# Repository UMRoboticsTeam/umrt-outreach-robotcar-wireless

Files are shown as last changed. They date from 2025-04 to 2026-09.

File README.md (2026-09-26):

# umrt-outreach-robotcar-wireless - elegoo-kit-face
Showcase program for the outreach car with wireless camera and control with the Elegoo Smart Robot Car Kit v4.0

The UI lets you control the car using the arrow keys (or controller) and displays a POV through the car's camera.
This repo also includes files to convert this into a POV soccer bot.

## elegoo-kit-face
This branch uses a modified version of the Elegoo Smart Robot Kit, replacing the ultrasonic sensor with an I2C OLED 128x64 Display.

<!-- ![alt text](docs/face-car.png) -->


This branch also contains the 3D printable files needed for the display modification.

### Additional Materials:
* I2C OLED Display 128x64
* 4x pin wires male to female
* 3D Printed Parts (files under ./3d-models)

The smart robot car kit shield contains a pin header for the gyroscope, which contains I2C communication pins A4 and A5. The gyroscope is not used in this program, so you can remove the gyroscope and use the pin header for OLED communication.

<!-- ![alt text](image-1.png) -->


### Soccer Bot
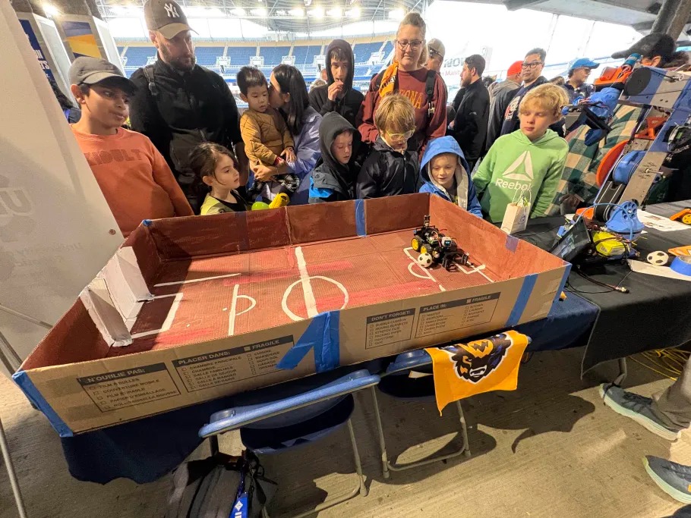
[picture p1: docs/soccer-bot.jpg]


*Soccer bot attechment in 3d-models/sumo_soccer_catch.3mf*

### Elegoo Smart Robot Car Kit v4.0

<!-- ![alt text](docs/smartrobotv4.0.png) -->
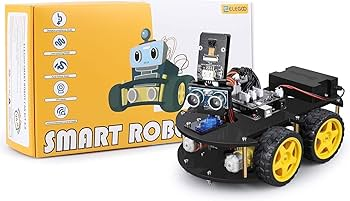
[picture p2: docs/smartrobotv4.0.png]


### Customized UI

<!-- ![alt text](docs/complete_ui.png) -->
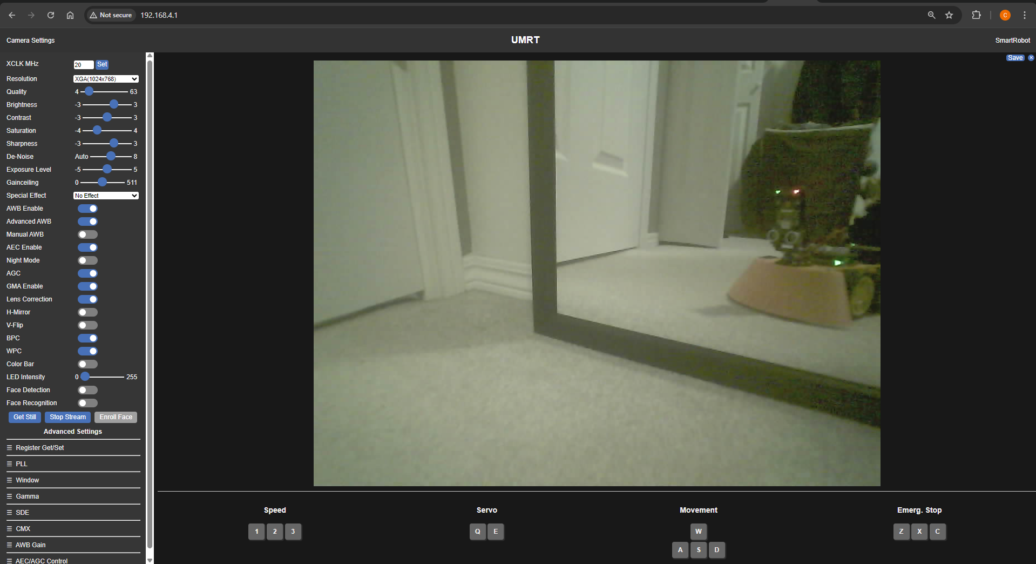
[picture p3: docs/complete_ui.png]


Has programs for:
* ESPCAM wireless webserver
* Robot car controller

## Source Code
[ELEGOO Smart Robot Car Kit v4.0 Tutorial](https://www.elegoo.com/blogs/arduino-projects/elegoo-smart-robot-car-kit-v4-0-tutorial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)
* Contains base code for motor controller - Be sure to check **Project Specifics**!

[ELEGOO Smart Robot Car V4.0 with Camera: Upload code to the camera module](https://www.elegoo.com/blogs/learn/elegoo-smart-robot-car-v4-0-with-camera-upload-code-to-the-camera-module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)
* Contains **UPDATED** camera code for the ESP32S3 Camera V1.0.

## Project Specifics
The template programs change depending on your specific parts. 
* ESP Camera: ```Elegoo ESP32S3 Camera v1.0```
* Motor Driver: ```TB6612```
* Gyro Module: ```MPU6050```

# car-driver
Arduino IDE Configuration:
* Board: ```Arduino UNO```

**Features:**  
* Adds OLED face functionality
* Improved UART communication from ESP32
* Added joystick motor control commands

<!-- ## ESP Camera Arduino IDE Setup -->
# ESP32_CameraServer_AP_2023_v1.3
Arduion IDE Configuration:
* Board Manager > Install ```esp32 by Espressif Systems v2.0.14```
* Configure Tools:
  * Board: ```ESP32S3 Dev Module```
  * USB CDC On Boot: ```Enabled```
  * Flash Size: ```8MB (64Mb)```
  * Partition Scheme: ```8M with spiffs (3MB APP/1.5MB SPIFFS)```
  * PSRAM ```OPI PSRAM```

The program creates a REST API to send json through to UART to the Arduino Uno to control the motors.

The served HTML handles all of the controls functionality. Based on the input, it will send json commands to the camera which forwards it to the robot car controller. The HTML file itself is stored as compressed GZ bytes under `camera_index.h`. To convert between a working HTML file and compressed bytes, use `converter.py`

## converter.py
Quick tool to convert HTML into compressed GZ bytes.

Used to compress **camera_index.html** into **camera_index.h**, to be compiled into the ESP32 webserver.
```
> python ./converter.py html_to_txt
```

`camera_index.h` and its variables are referenced during compilation, which stores all of the compressed HTML files.

To run the decompression process (`camera_index.h` to `camera_index.html`):
```
> python ./converter.py txt_to_html
```

# Usage
1. Turn on the power supply on the car, which powers both the car controller and the camera
2. Connect to the wifi called ```UMRT-CAR-XXXXXXXXXXXX```

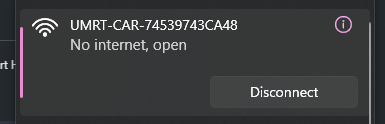
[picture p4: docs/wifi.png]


3. Open a browser and connect to ```192.168.4.1```
4. Configure settings by clicking the text in the top left
5. control the robot with your keyboard
  
| Key | Command |
|---|-----|
| Up | Move Forward |
| Down | Move Backward |
| Left | Turn Left |
| Right | Turn Right |
| Z, X, C | Emergency Stop |

Or connect a controller with a joystick! It can be used with one of them.  
The program assumes you will use:
* The first controller attached to the host device
* The axes [0] and [1] published by the controller

## Troubleshooting:
* If input is a little laggy: try turning it off and on again
* If the motor driver is stuck: try resetting it
* If the camera feed stops: try restarting car and browser

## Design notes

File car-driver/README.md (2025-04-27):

# car-driver

Custom car driver code for an Arduino UNO controlled by ESP32S3 Camera

Features expressive eyes powered by [Flux Garage's RoboEyes](https://github.com/FluxGarage/RoboEyes/) to add personality to the bot.

# Hardware
* Arduino UNO
* ESP32S3 Camera
* L298N Motor Driver (With 12V Power Supply)
* 4 Motors
* 128x64 I2C SSD1306 OLED Display
* Single servo motor

# Libraries

OLED Eyes:
https://github.com/FluxGarage/RoboEyes/

Motor Driver Lib:
https://github.com/AndreaLombardo/L298N

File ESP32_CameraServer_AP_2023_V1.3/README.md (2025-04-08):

# ESP32 CameraServer
Hosts webpage and REST API to pass json commands through UART to motor driver

I believe in older versions this code used ESP-FACE included in Core 2.0.0 and below, but its not included here. ESP Core 2.0.14 is required for ESP32-S3.

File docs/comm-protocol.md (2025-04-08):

# Communication Protocol
### ELEGOO - Smart Robot Car V4.0 With Camera
Copied from `Communication protocol for Smart Robot Car.pdf`

This was initially for the serial communication to the smart car, but since the REST API is implemented on the camera web server, you just need to send a POST request to the `/json_command` endpoint with your json command.

Not all commands are tested. 

# Motor
```json
{"H": ID, "N": 1, "D1": selection, "D2": speed, "D3": direction}
```
Select the motor to set the rotation direction and speed

| Parameter | Name | Description |
|----|-|-|
| D1 | Selection | 0: All Motors<br>1: Left Motors<br>2: Right Motors |
| D2 | Speed | Motor Speed 0-255 |
| D3 | Direction | 0: Clockwise<br>1: Counterclockwise |

```json
{"H": ID, "N": 3, "D1": direction, "D2": speed}
```
Set the direction and speed of the car
| Parameter | Name | Description |
|-|-|-|
| D1 | Direction | 1: Turn Left<br>2: Turn Right<br>3: Forward<br>4: Back |
| D2 | Speed | 0-255 |

```json
{"H": ID, "N": 3, "D1": left_speed, "D2": right_speed}
```
Set the speed of the left and right motors separately
| Parameter | Name | Description |
|-|-|-|
| D1 | Left Motor Speed | 0-255 |
| D2 | Right Motor Speed | 0-255 |

# Servo Motor
```json
{"H": ID, "N": 5, "D1": servo_id, "D2": angle}
```
Set the rotation angle of the servo motor
| Parameter | Name | Description |
|-|-|-|
| D1 | Servo ID | 0 or 1 |
| D2 | Rotation Angle | 0-180 |

## Camera Rotation (Wrapper of Servo Motor?)
```json
{"N": 106, "D1": direction}
```
Set the rotation direction of the camera
| Parameter | Name | Description |
|-|-|-|
| D1 | Direction | 1: Up<br>2: Down<br>3: Left<br>4: Right  |

# Clear Mode
```json
{"N": 100}
```
Clear all functions being executed.
```json
{"H": ID, "N": 110}
```
Clears all functions being executed, and does not enter standby mode

# Switch Car Mode
```json
{"N": 101, "D1": mode}
```
Switch the car mode
| Parameter | Name | Description |
|-|-|-|
| D1 | Mode | 1: Tracking mode<br>2: Obstacle-avoidance mode<br>3: Follow mode |

# Joystick Movement
```json
{"N": 102, "D1": direction, "D2": speed}
```
Make the car move in a certain direction
| Parameter | Name | Description |
|-|-|-|
| D1 | Direction | 1: Forward<br>2: Back<br>3: Turn Left<br>4: Turn Right<br>5: Left Forward<br>6: Left Back<br>7:Right Forward<br>8: Right Back|
| D2 | Speed | 0-255 |

# Ultrasonic Module
```json
{"H": ID, "N": 21, "D1": option}
```
Check whether an obstacle is detected
| Parameter | Name | Description |
|-|-|-|
| D1 | option | 1: Obstacle is detected? Returns `{ID_false}` or `{ID_true}`<br>2: Sensor Value? Returns `{ value }` |

# Infared Module
```json
{"H": ID, "N": 22, "D1": infared_id}
```
Check the value of the infared sensor
| Parameter | Name | Description |
|-|-|-|
| D1 | Infared ID | 0: Left Sensor<br>1: Middle Sensor<br>2: Right Sensor |
Returns `{ ID_ value }`

```json
{"H": ID, "N": 23}
```
Check if the car leaves the ground
Returns `{ ID_ false }` or `{ ID_ true }`

# Threshold Adjustment
```json
{"N": 104, "D1": value}
```
Adjust the tracking sensitivity of the car
| Parameter | Name | Description |
|-|-|-|
| D1 | Value | 50-1000 |

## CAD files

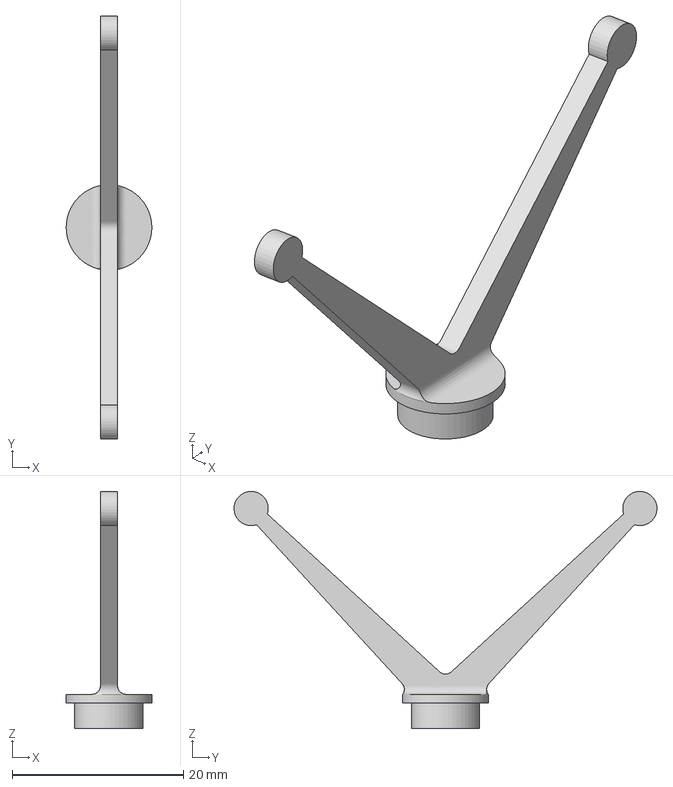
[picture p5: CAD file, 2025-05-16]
3d-models/oled-head-antenna.3mf
10.0 x 49.4 x 27.7 mm

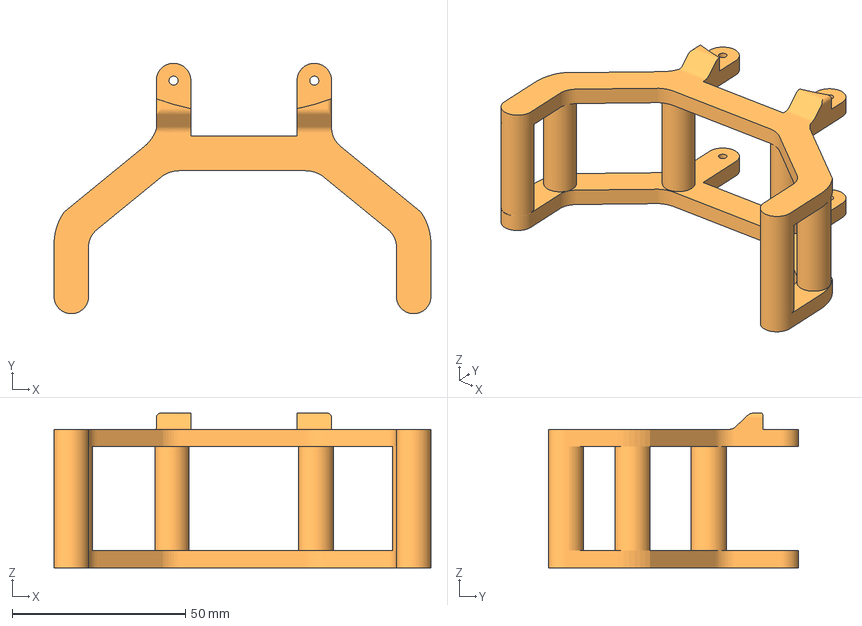
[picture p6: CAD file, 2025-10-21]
sumo_soccer_catch.3mf
108.8 x 72.2 x 44.7 mm

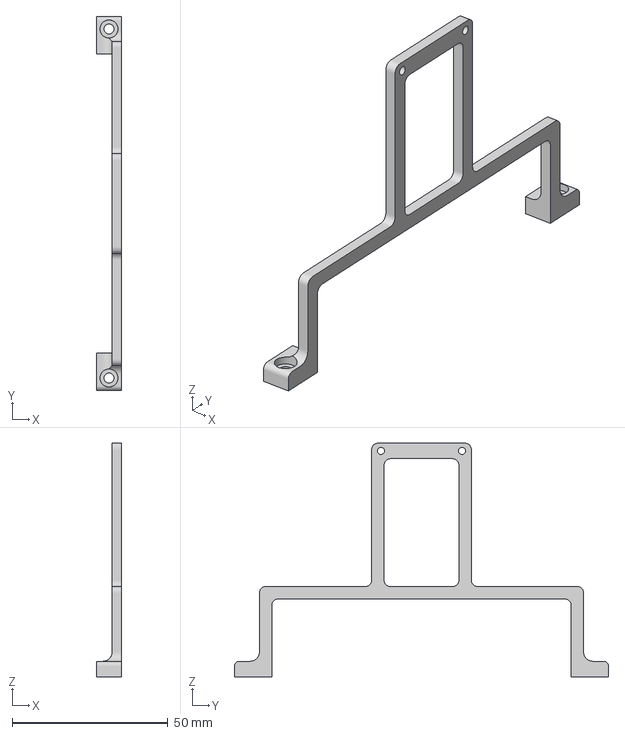
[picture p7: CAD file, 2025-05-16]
3d-models/esp-cam-mount-v2.3mf
8.00 x 120.0 x 75.0 mm

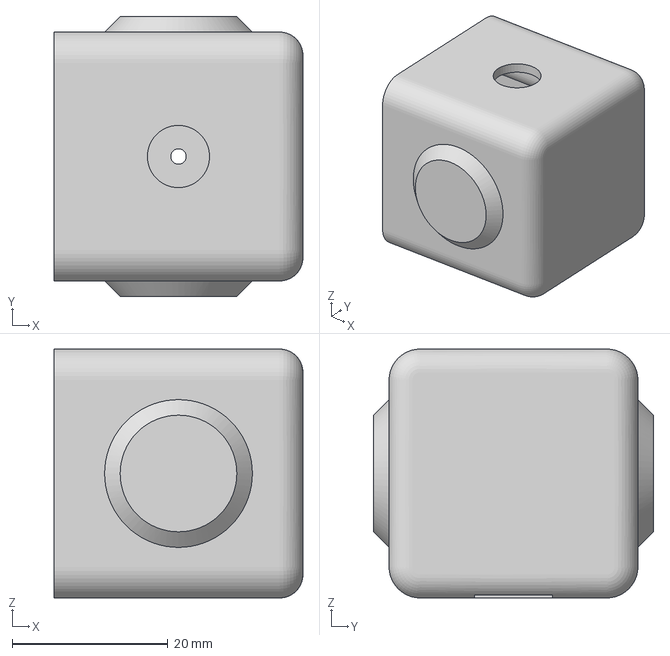
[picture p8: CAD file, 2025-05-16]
3d-models/oled-head-v2.3mf
32.0 x 36.0 x 32.0 mm

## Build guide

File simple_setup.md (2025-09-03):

# Simple Setup

### 1) Turn car on
Turn battery switch ON  
Ensure switch on Arduino hat is set to CAM, not UPLOAD

### 2) Connect to Car's Wifi
Use your device to connect to its WIFI, it should be `UMRT-CAR-1`
pwd is `umrt2025`

Once your connected, the green LED on the ESP32 should go from FLASHING to SOLID

### 3) Connect to UI
Open a browser and connect to `192.168.4.1`  
You should see the UMRT browser with the camera feed

### 4) Configure
To configure the speed, click "SmartRobot" in the top left corner. The first option is "Speed".  
The default speed is 60 and can go up to 255.

### 5) Controlling
The device is controlled with the arrow keys AND NOW A JOYSTICK!  
If controlled with a controller connected through USB, it only uses one joystick. Probably the leftside joystick.

### Debugging
Camera feed cut out? Restart car  
Car not responding to commands? Restart Car  
Car stuck driving? Restart car  

Sometimes if its just the motors that are tweaking (not the camera), you can try pressing the red button on the Arduino to restart just the motor controller

If you do restart, the speed also defaults back to 60

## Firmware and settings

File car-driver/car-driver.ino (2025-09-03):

//***********************************************************************************************
//  
//  
//  FluxGarage Robot Eyes Library
//  https://github.com/FluxGarage/RoboEyes/
//
//  L298N Motor Driver Library
//  https://github.com/AndreaLombardo/L298N
//
//
//
//***********************************************************************************************
#include <Adafruit_SSD1306.h>
#include <Servo.h>

#define SCREEN_WIDTH 128
#define SCREEN_HEIGHT 64
// Declaration for an SSD1306 display connected to I2C (SDA, SCL pins)
#define OLED_RESET -1
Adafruit_SSD1306 display(SCREEN_WIDTH, SCREEN_HEIGHT, &Wire, OLED_RESET);

// #include "L298NX2.h"
#include "motor_driver.h"
DeviceDriverSet_Motor AppMotor;

#include "FluxGarage_RoboEyes.h"  // include after initializing display
roboEyes roboEyes; // create eyes



// #define EN_A 5
// #define IN1_A 7
// #define IN2_A 6

// #define IN1_B 9
// #define IN2_B 8
// #define EN_B 11


#define SERVO_PIN 11


// Initialize both motors
// L298NX2 myMotors(EN_A, IN1_A, IN2_A, EN_B, IN1_B, IN2_B);


Servo HeadServo;

void setup() {

  // wdt_reset();
  // Increase PWM frequency for Timer 1 (pins 9 and 10)
  // TCCR1B = TCCR1B & 0b11111000 | 0x01; // Set Timer 1 to ~31kHz

  // Increase PWM frequency for Timer 2 (pins 3 and 11)
  // TCCR2B = TCCR2B & 0b11111000 | 0x01; // Set Timer 2 to ~31kHz


  Serial.begin(9600);


  AppMotor.DeviceDriverSet_Motor_Init();

  HeadServo.attach(SERVO_PIN);
  HeadServo.write(90);

  // OLED Display
  
  if(!display.begin(SSD1306_SWITCHCAPVCC, 0x3C)) {
    Serial.println(F("SSD1306 allocation failed"));
    for(;;);
  }

  // Startup robo eyes
  roboEyes.begin(SCREEN_WIDTH, SCREEN_HEIGHT, 100); // screen-width, screen-height, max framerate - 60-100fps are good for smooth animations
  roboEyes.setPosition(DEFAULT); // eye position should be middle center
  roboEyes.close(); // start with closed eyes 
  
  roboEyes.setAutoblinker(ON, 3, 2); // Start auto blinker animation cycle -> bool active, int interval, int variation -> turn on/off, set interval between each blink in full seconds, set range for random interval variation in full seconds
  roboEyes.setIdleMode(ON, 2, 2); // Start idle animation cycle (eyes looking in random directions) -> turn on/off, set interval between each eye repositioning in full seconds, set range for random time interval variation in full seconds
} 


unsigned long next_trigger_1;
unsigned long next_trigger_2;

void loop() {
  // Handle commands from serial
  handleCmdJson();

  // Trigger random animations every 4s
  if (millis() > next_trigger_1) {
    next_trigger_1 = millis() + 3000 + random(0, 4) * 1000; // 3s-5s
    
    // change eye shape
    // roboEyes.anim_laugh();
    roboEyes.setMood(random(0, 2) * 3); // 0-Default, 1-Tired, 2-Angry, 3-Happy
    roboEyes.setCuriosity(random(0, 2));
  }

  if (millis() > next_trigger_2) {
    next_trigger_2 = millis() + 2000 + random(0, 3) * 1000; // 2s-4s
    // move servo slightly (+-15deg)

    // roboEyes.eyeLxNext = random(roboEyes.getScreenConstraint_X());
    // roboEyes.eyeLyNext = random(roboEyes.getScreenConstraint_Y());
    HeadServo.write(random(75, 106));
  }
  

  // Update robot eyes
  roboEyes.update();
  
  
} 


// W {"N":3,"D1":3,"D2":255}
// S {"N":3,"D1":4,"D2":255}
// A {"N":102,"D1":3,"D2":255}
// D {"N":102,"D1":4,"D2":255}


// WA {"N":102,"D1":5,"D2":255}
// WD {"N":102,"D1":7,"D2":255}
// SA {"N":102,"D1":6,"D2":255}
// SD {"N":102,"D1":8,"D2":255}


// Q {"H":1,"N":5,"D1":1,"D2":120}
// E {"H":1,"N":5,"D1":1,"D2":90}

// STOP {"N":1,"D1":0,"D2":0,"D3":1}

void handleCmdJson() {
  static String inputString = "";

  if (Serial.available()) {
    char incomingChar = Serial.read();

    if (incomingChar == '\n') { // End of command
      inputString.trim(); // Remove any leading/trailing whitespace

      Serial.print(F("Received: "));
      Serial.println(inputString);

      // Parse the command
      int command = 0, d1 = 0, d2 = 0, d3 = 0, d4 = 0;
      int parsed = sscanf(inputString.c_str(), "%d %d %d %d %d", &command, &d1, &d2, &d3, &d4);

      if (parsed >= 1) {
        Serial.print(F("Command: "));
        Serial.println(command);

        // Handle the command
        switch (command) {
          case 1:
            handleCmd1(d1, d2, d3);
            break;
          case 3:
            handleCmd3(d1, d2);
            break;
          case 102:
            handleCmd102(d1, d2);
            break;
          
          case 69:
            handleCmd69(d1, d2, d3, d4);
            break;
          default:
            Serial.print(F("Unknown command: "));
            Serial.println(command);
            break;
        }
      } else {
        Serial.println(F("Invalid command format."));
      }

      inputString = ""; // Clear the buffer
    } else {
      inputString += incomingChar; // Append character to the input buffer
    }
  }
} 



void handleCmd1(int selection, int speed, int direction) {

  // if (direction == 0) {
  //   if (selection != 2) {
  //     // Left Side
  //     // myMotors.setSpeedA(speed);
  //     // myMotors.forwardA();
  //     // AppMotor.DeviceDriverSet_Motor_control(true, speed, false, speed, true);

  //     lookLeft();
  //   } 
  //   if (selection != 1) {
  //     // Right Side
  //     // myMotors.setSpeedB(speed);
  //     // myMotors.forwardB();
  //     // AppMotor.DeviceDriverSet_Motor_control(false, speed, true, speed, true);

  //     lookRight();
  //   }
  // }
  // else {
  //   if (selection != 2) {
  //     // Left Side
  //     // myMotors.setSpeedA(speed);
  //     // myMotors.backwardA();

  //     lookLeft();
  //   } 
  //   if (selection != 1) {
  //     // Right Side
  //     // myMotors.setSpeedB(speed);
  //     // myMotors.backwardB();

  //     lookRight();
  //   }
  // }


  // TO DO:
  // IMPLEMENT THIS PROPERLY
  // RIGHT NOW ITS ONLY BEING USED FOR STOPPING THE MOTORS
  // SO THIS IS FINE
  if (selection == 0) {
    // all motors
    if (direction == 1) {
      // clockwise?
      AppMotor.DeviceDriverSet_Motor_control(true, speed, true, speed, true);
    }
    else {
      // counterclockwise?
      AppMotor.DeviceDriverSet_Motor_control(false, speed, false, speed, true);
    }
  }
  if (selection == 1) {
    // LEFT
    if (direction == 1) {
      // clockwise?
      AppMotor.DeviceDriverSet_Motor_control(true, speed, direction_void, 0, true);
    }
    else {
      // counterclockwise?
      AppMotor.DeviceDriverSet_Motor_control(false, speed, direction_void, 0, true);
    }
  }
  if (selection == 2) {
    // RIGHT
    if (direction == 1) {
      // clockwise?
      AppMotor.DeviceDriverSet_Motor_control(direction_void, 0, true, speed, true);
    }
    else {
      // counterclockwise?
      AppMotor.DeviceDriverSet_Motor_control(direction_void, 0, false, speed, true);
    }
  }
  
  if (speed == 0) {lookIdle();}
  Serial.println("Handled CMD 1");
}

void handleCmd3(int direction, int speed) {

  // myMotors.setSpeed(speed);
  if (direction == 3) {
    // 3 - forward
    // myMotors.forward();
    AppMotor.DeviceDriverSet_Motor_control(true, speed, true, speed, true);

    lookStraight();
  }
  else if (direction == 4) {
    // 4 - backward
    // myMotors.backward();
    AppMotor.DeviceDriverSet_Motor_control(false, speed, false, speed, true);

    lookStraight();
  }
  else if (direction == 1) {
    // 1 - turn left
    // myMotors.backwardA();
    // myMotors.forwardB();
    AppMotor.DeviceDriverSet_Motor_control(true, speed, false, speed, true);

    lookLeft();
  }
  else if (direction == 2) {
    // 2 - turn right
    // myMotors.forwardA();
    // myMotors.backwardB();
    AppMotor.DeviceDriverSet_Motor_control(false, speed, true, speed, true);

    lookRight();
  }

  if (speed == 0) {lookIdle();}
  Serial.println("Handled CMD 3");
}

void handleCmd69(int dirA, int spdA, int dirB, int spdB) {

  AppMotor.DeviceDriverSet_Motor_control(dirA, spdA, dirB, spdB, true);
  
  if (spdA == 0 && spdB == 0) {
    lookIdle();
  }
}

void handleCmd102(int direction, int speed) {

  // myMotors.setSpeed(speed);
  if (direction == 1) {
    // 1 - Forward
    // myMotors.setSpeed(speed);
    // myMotors.forward();
    AppMotor.DeviceDriverSet_Motor_control(true, speed, true, speed, true);

    lookStraight();
  }
  if (direction == 2) {
    // 2 - Backward
    // myMotors.setSpeed(speed);
    // myMotors.backward();
    AppMotor.DeviceDriverSet_Motor_control(false, speed, false, speed, true);

    lookStraight();
  }
  if (direction == 3) {
    // 3 - Turn Left
    // myMotors.setSpeed(speed);
    // myMotors.forwardA();
    // myMotors.backwardB();
    AppMotor.DeviceDriverSet_Motor_control(true, speed, false, speed, true);
    
    lookLeft();
  }
  if (direction == 4) {
    // 4 - Turn right
    // myMotors.setSpeed(speed);
    // myMotors.backwardA();
    // myMotors.forwardB();
    AppMotor.DeviceDriverSet_Motor_control(false, speed, true, speed, true);

    lookRight();
  }
  if (direction == 5) {
    // 5 - Left Forward
    // myMotors.setSpeedA(speed);
    // myMotors.setSpeedB(speed / 2);
    // myMotors.forward();
    AppMotor.DeviceDriverSet_Motor_control(true, speed, true, speed / 4, true);

    lookLeft();
  }
  if (direction == 6) {
    // 6 - Left Backward
    // myMotors.setSpeedA(speed);
    // myMotors.setSpeedB(speed / 2);
    // myMotors.backward();
    AppMotor.DeviceDriverSet_Motor_control(false, speed, false, speed / 4, true);

    lookLeft();
  }
  if (direction == 7) {
    // 7 - Right Forward
    // myMotors.setSpeedA(speed / 2);
    // myMotors.setSpeedB(speed);
    // myMotors.forward();
    AppMotor.DeviceDriverSet_Motor_control(true, speed / 4, true, speed, true);

    lookRight();
  }
  if (direction == 8) {
    // 8 - Right Backward
    // myMotors.setSpeedA(speed / 2);
    // myMotors.setSpeedB(speed);
    // myMotors.backward();
    AppMotor.DeviceDriverSet_Motor_control(false, speed / 4, false, speed, true);

    lookRight();
  }
  
  if (speed == 0) {lookIdle();}
  Serial.println("Handled CMD 102");
}



void lookStraight() {
  roboEyes.idleAnimationTimer = -1; // hold idle animation
  roboEyes.setPosition('X');
  HeadServo.write(90);
  next_trigger_2 = 0;  // continue servo animation
}
void lookLeft() {
  roboEyes.idleAnimationTimer = -1; // hold idle animation
  roboEyes.setPosition(W);
  HeadServo.write(150);
  next_trigger_2 = -1;  // hold servo animation
}
void lookRight() {
  roboEyes.idleAnimationTimer = -1; // hold idle animation
  roboEyes.setPosition(E);
  HeadServo.write(30);
  next_trigger_2 = -1;  // hold servo animation
}
void lookIdle() {
  // continue idle animation
  roboEyes.idleAnimationTimer = 0;  // resume idle animation
  HeadServo.write(90);
  next_trigger_2 = 0; // continue servo animation
}

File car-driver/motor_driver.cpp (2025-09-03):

#include "motor_driver.h"

/*Motor control*/
void DeviceDriverSet_Motor::DeviceDriverSet_Motor_Init(void)
{
  pinMode(PIN_Motor_PWMA, OUTPUT);
  pinMode(PIN_Motor_PWMB, OUTPUT);
  pinMode(PIN_Motor_AIN_1, OUTPUT);
  pinMode(PIN_Motor_BIN_1, OUTPUT);
  pinMode(PIN_Motor_STBY, OUTPUT);
}

#if _Test_DeviceDriverSet
void DeviceDriverSet_Motor::DeviceDriverSet_Motor_Test(void)
{
  //A...Right
  //B...Left
  digitalWrite(PIN_Motor_STBY, HIGH);

  digitalWrite(PIN_Motor_AIN_1, HIGH);
  analogWrite(PIN_Motor_PWMA, 100);
  digitalWrite(PIN_Motor_BIN_1, HIGH);
  analogWrite(PIN_Motor_PWMB, 100);
  delay_xxx(1000);

  digitalWrite(PIN_Motor_STBY, LOW);
  delay_xxx(1000);
  digitalWrite(PIN_Motor_STBY, HIGH);
  digitalWrite(PIN_Motor_AIN_1, LOW);
  analogWrite(PIN_Motor_PWMA, 100);
  digitalWrite(PIN_Motor_BIN_1, LOW);
  analogWrite(PIN_Motor_PWMB, 100);

  delay_xxx(1000);
}
#endif

/*
 Motor_control：AB / movement direction and speed
*/
void DeviceDriverSet_Motor::DeviceDriverSet_Motor_control(boolean direction_A, uint8_t speed_A, //Group A motor parameters
                                                          boolean direction_B, uint8_t speed_B, //Group B motor parameters
                                                          boolean controlED                     //AB enable setting (true)
                                                          )                                     //Motor control
{

  if (controlED == control_enable) //Enable motot control？
  {
    digitalWrite(PIN_Motor_STBY, HIGH);
    { //A...Right

      switch (direction_A) //movement direction control
      {
      case direction_just:
        digitalWrite(PIN_Motor_AIN_1, HIGH);
        analogWrite(PIN_Motor_PWMA, speed_A);
        break;
      case direction_back:

        digitalWrite(PIN_Motor_AIN_1, LOW);
        analogWrite(PIN_Motor_PWMA, speed_A);
        break;
      case direction_void:
        // analogWrite(PIN_Motor_PWMA, 0);
        // digitalWrite(PIN_Motor_STBY, LOW);
        // analogWrite(PIN_Motor_PWMA, speed_A);
        break;
      default:
        analogWrite(PIN_Motor_PWMA, 0);
        digitalWrite(PIN_Motor_STBY, LOW);
        break;
      }
    }

    { //B...Left
      switch (direction_B)
      {
      case direction_just:
        digitalWrite(PIN_Motor_BIN_1, HIGH);

        analogWrite(PIN_Motor_PWMB, speed_B);
        break;
      case direction_back:
        digitalWrite(PIN_Motor_BIN_1, LOW);
        analogWrite(PIN_Motor_PWMB, speed_B);
        break;
      case direction_void:
        // analogWrite(PIN_Motor_PWMB, 0);
        // digitalWrite(PIN_Motor_STBY, LOW);
        // analogWrite(PIN_Motor_PWMB, speed_B);
        break;
      default:
        analogWrite(PIN_Motor_PWMB, 0);
        digitalWrite(PIN_Motor_STBY, LOW);
        break;
      }
    }
  }
  else
  {
    digitalWrite(PIN_Motor_STBY, LOW);
    return;
  }
}

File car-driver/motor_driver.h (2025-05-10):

#include <Arduino.h>

/*Motor*/
class DeviceDriverSet_Motor
{
public:
  void DeviceDriverSet_Motor_Init(void);
#if _Test_DeviceDriverSet
  void DeviceDriverSet_Motor_Test(void);
#endif
  void DeviceDriverSet_Motor_control(boolean direction_A, uint8_t speed_A, //Group A motor parameters
                                     boolean direction_B, uint8_t speed_B, //Group B motor parameters
                                     boolean controlED                     //AB enable setting (true)
  );                                                                       //motor control
private:
  // #define PIN_Motor_PWMA 5
  // #define PIN_Motor_PWMB 6
  // #define PIN_Motor_STBY 8
  // #define PIN_Motor_BIN_1 7
  // #define PIN_Motor_AIN_1 9
//TB6612
#define PIN_Motor_PWMA 5
#define PIN_Motor_PWMB 6
#define PIN_Motor_BIN_1 8
#define PIN_Motor_AIN_1 7
#define PIN_Motor_STBY 3
public:
#define speed_Max 255
#define direction_just true
#define direction_back false
#define direction_void 3

#define Duration_enable true
#define Duration_disable false
#define control_enable true
#define control_disable false
};

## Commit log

2025-04-06 Added handlers for json commands
    JSON commands are directly sent to the robot car controller through UART
2025-04-07 Updated converter.py to write directly to camera_index.h
2025-04-26 Updated for I2C SSD1306 OLED Display
2025-04-26 Added motor driver
2025-04-26 Updated Camera and controls page
    Commands updated from JSON to TEXT to optimize memory on uno
2025-04-27 Added servo neck control, update README
2025-04-28 Fixed motor drive direction
    [car-driver.ino]
2025-05-09 Returned ESP32 camera transmitting JSON messages
2025-05-10 Updated car-driver.ino to use elegoo motor drivers
2025-05-10 Added idle servo animation
2025-05-10 minor tweaks to driver turn speed
2025-05-16 Added 3D models for face modifications
    [esp-cam-mount-v2.3mf, oled-head-antenna.3mf, oled-head-v2.3mf]
2025-10-21 Uploaded soccer catch for soccer bot, removed old files
    [sumo_soccer_catch.3mf]
2025-10-21 Updated README.md, added soccer bot mods
    [sumo_soccer_catch.3mf]
